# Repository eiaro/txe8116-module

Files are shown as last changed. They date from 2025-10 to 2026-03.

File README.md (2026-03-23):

# TXE8116 Module

Open-source hardware module for the TXE8116 — a 16-bit SPI I/O expander with two 8-bit ports, configurable push-pull/open-drain outputs, pull resistors, interrupt support, and per-pin glitch filtering.

## Repository Structure

```
txe8116-module/
├── hardware/          # KiCad schematic and PCB (CC BY-SA 4.0)
├── firmware/          # Driver and example code (MIT)
│   ├── esp32/         # ESP-IDF example
│   ├── zephyr/        # Zephyr RTOS examples
│   ├── raspberrypi/   # Python driver and C example
│   ├── arduino/       # Arduino example
│   └── beaglebone/    # BeagleBone C example
└── docs/              # Wiring guides
```

## Firmware

### ESP32 (ESP-IDF)

Uses the [`eiaro/txe81xx`](https://components.espressif.com/components/eiaro/txe81xx) component from the ESP component registry.

```bash
cd firmware/esp32/esp-idf/txe8116_idf
idf.py build flash monitor
```

See [`firmware/esp32/esp-idf/txe8116_idf/README.md`](firmware/esp32/esp-idf/txe8116_idf/README.md).

### Zephyr RTOS

Uses the [`xylon-labs/zephyr-txe81xx`](https://github.com/xylon-labs/zephyr-txe81xx) driver module.

| Example | Description |
|---|---|
| [`firmware/zephyr/basic_gpio`](firmware/zephyr/basic_gpio/README.md) | Polling — LED mirrors button state |
| [`firmware/zephyr/gpio_interrupt`](firmware/zephyr/gpio_interrupt/README.md) | Interrupt-driven — LED toggles on button events |

```bash
west build -b nucleo_l476rg firmware/zephyr/basic_gpio
```

### Raspberry Pi (Python)

```bash
cd firmware/raspberrypi/python
python3 example.py
```

See [`firmware/raspberrypi/python/README.md`](firmware/raspberrypi/python/README.md).

## Hardware

KiCad 8.x project in [`hardware/txe8116-module/`](hardware/txe8116-module/README.md). Fabrication files (Gerbers, BOM, pick & place) are in `hardware/txe8116-module/fabrication/`.

## License

- **Hardware** (`hardware/`): [CC BY-SA 4.0](hardware/LICENSE)
- **Firmware / Software** (`firmware/`): [MIT](firmware/LICENSE)

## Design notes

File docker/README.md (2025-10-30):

# KiBot Docker Image for txe8116-module

This Docker image contains KiBot with KiCad 9.0.5 to ensure consistent
versioning between local development and CI/CD.

## Why?

We use KiCad 9.0.5 locally, but the standard KiBot Docker image uses 9.0.1,
which can cause incompatibility issues.

## Usage

### Local Development
```bash
# Build the image
docker build -t txe8116-kibot:latest docker/

# Run ERC/DRC
docker run --rm -v $(pwd):/workspace txe8116-kibot:latest \
  -c hardware/kibot.yaml \
  -b hardware/txe8116-module.kicad_pcb
```

### In CI/CD
The image is automatically built and published to GitHub Container Registry
when changes are pushed to the main branch.

## Updating KiCad Version

Edit `Dockerfile` and update the KiCad version as needed.

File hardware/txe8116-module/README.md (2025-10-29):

# TXE8116 Module — Hardware

KiCad project for the TXE8116 SPI 16-bit I/O expander module.

## Layout
- `kicad/` – editable sources (schematic, PCB, libs)
- `fabrication/` – Gerbers, drill, BOM, pick&place (for production)
- `docs/` – PDFs, renders, drawings

## Build notes
- KiCad 8.x recommended
- Generate fab files to `fabrication/` (Gerbers, drill, BOM, pos)
- Export PDFs of schematic/PCB to `docs/pdf/`

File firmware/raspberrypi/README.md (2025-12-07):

# TXE8116 - Raspberry Pi

Simple guide to get started with TXE8116 on Raspberry Pi.

## Quick Start

### 1. Enable SPI

```bash
sudo raspi-config
```
- Navigate to: **Interface Options → SPI → Enable**
- Reboot: `sudo reboot`

### 2. Verify SPI

After reboot:
```bash
ls /dev/spidev*
```
You should see `/dev/spidev0.0` and `/dev/spidev0.1`

### 3. Wiring

Connect TXE8116 to Raspberry Pi:

| TXE8116 Pin | RPi Pin | BCM GPIO | Function |
|---|---|---|---|
| VCC | Pin 1 | - | 3.3V Power |
| GND | Pin 6 | - | Ground |
| CS | Pin 24 | GPIO 8 | SPI CE0 |
| SCK | Pin 23 | GPIO 11 | SPI SCLK |
| SDI (MOSI) | Pin 19 | GPIO 10 | SPI MOSI |
| SDO (MISO) | Pin 21 | GPIO 9 | SPI MISO |
| INT | Pin 11 | GPIO 17 | Interrupt (optional*) |
| RESET | Pin 15 | GPIO 22 | Reset (optional*) |

*Note: INT and RESET pins are optional but current hardware revision requires external pull-up resistors if not used. See [#8](https://github.com/eiaro/txe8116-module/issues/8) and [#9](https://github.com/eiaro/txe8116-module/issues/9) for details.

### 4. Test with Python

Install dependencies:
```bash
pip3 install spidev
```

Run example:
```bash
cd python/examples
python3 txe8116_spidev_example.py
```

## Languages & Frameworks

- **[Python](python/)** - High-level examples with spidev
- **[C](c/)** - Direct SPI access with `/dev/spidev`

## Troubleshooting

**SPI not enabled:**
```bash
# Check if SPI is enabled
lsmod | grep spi
# Should show: spi_bcm2835

# Alternative: add to /boot/config.txt
dtparam=spi=on
```

**Permission denied:**
```bash
# Add user to spi group
sudo usermod -a -G spi $USER
# Logout and login again
```

**Device not responding:**
- Check wiring (especially GND connection)
- Verify VCC is 3.3V (not 5V!)
- Measure SPI clock frequency with oscilloscope
- Check TXE8116 datasheet for timing requirements

## Resources

- [Raspberry Pi SPI Documentation](https://www.raspberrypi.com/documentation/computers/raspberry-pi.html#serial-peripheral-interface-spi)
- [TXE8116 Datasheet](../../docs/datasheet/)
- [Wiring Diagram](../../docs/wiring_rpi.md)

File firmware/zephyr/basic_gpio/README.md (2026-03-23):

# TXE8116 Basic GPIO Sample (Zephyr)

Minimal Zephyr sample for the TXE8116 16-bit SPI I/O expander. Reads a button and mirrors the state to an LED in a polling loop.

## Requirements

- Zephyr RTOS v3.6 or later
- [xylon-labs/zephyr-txe81xx](https://github.com/xylon-labs/zephyr-txe81xx) driver module

## Hardware Setup

Board overlay provided for **STM32 Nucleo-L476RG** (`boards/nucleo_l476rg.overlay`).

| Signal | Pin |
|---|---|
| SPI1 CS | PA4  |
| RESET | PC6  |
| INT | PC7  |

| TXE Pin | Function |
|---|---|
| Pin 0 | LED (active low) |
| Pin 8 | Switch (active high, pull-down) |

## Build & Flash

```bash
west build -b nucleo_l476rg
west flash
```

## Behaviour

LED follows button state with a 50 ms polling interval.

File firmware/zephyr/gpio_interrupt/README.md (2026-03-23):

# TXE8116 GPIO Interrupt Sample (Zephyr)

Zephyr sample demonstrating interrupt-driven GPIO with the TXE8116 16-bit SPI I/O expander. The LED toggles on each button press and release.

## Requirements

- Zephyr RTOS v3.6 or later
- [xylon-labs/zephyr-txe81xx](https://github.com/xylon-labs/zephyr-txe81xx) driver module

## Hardware Setup

Board overlay provided for **STM32 Nucleo-L476RG** (`boards/nucleo_l476rg.overlay`).

| Signal | Pin |
|---|---|
| SPI1 CS | PA4  |
| RESET | PC6  |
| INT | PC7  |

| TXE Pin | Function |
|---|---|
| Pin 0 | LED (active low) |
| Pin 8 | Switch (active high, pull-down) |

A hardware glitch filter is enabled on the switch pin via `glitch-filter-pins` in the overlay.

## Build & Flash

```bash
west build -b nucleo_l476rg
west flash
```

## Behaviour

- Button press → LED toggles, logs `Switch: PRESSED`
- Button release → LED toggles, logs `Switch: RELEASED`
- Main thread sleeps indefinitely; all activity is interrupt-driven

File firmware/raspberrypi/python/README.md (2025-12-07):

# TXE8116 Python Driver

Python library for the TXE8116 16-bit SPI I/O expander on Raspberry Pi.

## Installation

```bash
# Install dependencies
sudo apt-get install python3-spidev python3-rpi.gpio

# Enable SPI
sudo raspi-config
# Interface Options → SPI → Enable
```

## Hardware Setup

### SPI Connections
- **VCC** → 3.3V
- **GND** → GND
- **SCLK** → GPIO11 (SCLK)
- **MOSI** → GPIO10 (MOSI)
- **MISO** → GPIO9 (MISO)
- **CS** → GPIO8 (CE0)
- **RESET** → GPIO22 (optional, recommended)

## Usage

```python
from txe8116 import TXE8116

# Initialize
io = TXE8116(bus=0, device=0, reset_pin=22)

# Configure Port 0 as all outputs
io.configure_port(port=0, direction=0xFF, push_pull=0x00)

# Write patterns
io.write_port(port=0, value=0xFF)  # All HIGH
io.write_port(port=0, value=0x00)  # All LOW

# Individual pin control
io.set_pin(port=0, pin=0)    # P0.0 HIGH
io.clear_pin(port=0, pin=0)  # P0.0 LOW
io.toggle_pin(port=0, pin=0) # Toggle P0.0

# Read inputs (set direction=0x00 first)
value = io.read_port(port=0)

# Clean up
io.close()
```

## Example

Run the example:
```bash
python3 example.py
```

## Notes

- **Direction**: `1` = output, `0` = input
- **Push-pull**: `0` = push-pull (default), `1` = open-drain
- **Ports**: Port 0 and Port 1, 8 pins each (16 total)

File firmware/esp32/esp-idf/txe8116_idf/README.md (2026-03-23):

# TXE8116 ESP-IDF Example

ESP-IDF example for the TXE8116 16-bit SPI I/O expander using the [`eiaro/txe81xx`](https://components.espressif.com/components/eiaro/txe81xx) component from the ESP component registry.

Demonstrates interrupt-driven I/O: a button on TXE Port 1 controls the blink rate of an LED on TXE Port 0.

## Requirements

- ESP-IDF v5.0 or later
- ESP32-C6 (or adjust pin definitions in `main/txe8116_idf.c`)

## Hardware Setup

| Signal | ESP32 GPIO |
|---|---|
| MOSI | GPIO7 |
| MISO | GPIO2 |
| CLK | GPIO6 |
| CS | GPIO10 |
| RESET  | GPIO3 |
| INT | GPIO4 |

| TXE Pin | Function |
|---|---|
| P0.0 | LED (active low) |
| P1.1 | Switch (active high, pull-down) |

## Build & Flash

```bash
idf.py build
idf.py flash monitor
```

The component manager will fetch `eiaro/txe81xx` automatically on first build.

## Behaviour

- LED blinks slowly (300 ms) when button is released
- LED blinks fast (100 ms) when button is held
- Button state is read via TXE interrupt — no polling

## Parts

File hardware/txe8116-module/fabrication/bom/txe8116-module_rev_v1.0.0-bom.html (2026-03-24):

 | KiBot variants example
 | Schematic: txe8116-module Variant: default Revision: v1.0.0 Date: 2026-03-24_20-05-20 KiCad Version: 9.0.5+1 | Component Groups: 5 Component Count: 28 (per PCB) Fitted Components: 28 (per PCB) Number of PCBs: 1 Total Components: 28 (for 1 PCBs)
Row | References | Quantity Per PCB | Value | Footprint
1 | C3 | 1 | 100 nF | C_0603_1608Metric
2 | C4 | 1 | 4.7 µF | C_0603_1608Metric
3 | D1 D2 D3 D4 D5 D6 D7 D8 D9 D10 D11 D12 D13 D14 D15 D16 D17 D18 D19 D20 D21 D22 D23 | 23 | ESD9B5.0ST5G | D_SOD-923
4 | R1 R2 | 2 | 10 kΩ | R_0603_1608Metric
5 | U1 | 1 | TXE8116 | Texas_DGS0024A_TSSOP-24_3x6.1mm_P0.5mm
Color reference for columns:
KiCad Fields (default)
Generated Fields
User Fields

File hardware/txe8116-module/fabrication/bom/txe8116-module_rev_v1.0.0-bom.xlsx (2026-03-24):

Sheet: BoM
 |  | KiBot variants example
 |  | Schematic: | txe8116-module | Component Groups: | 5
 |  | Variant: | default | Component Count: | 28
 |  | Revision: | v1.0.0 | Fitted Components: | 28
 |  | Date: | 2026-03-24_20-05-20 | Number of PCBs: | 1
 |  | KiCad Version: | 9.0.5+1 | Total Components: | 28
Row | References | Quantity Per PCB | Value | Footprint
1 | C3 | 1 | 100 nF | C_0603_1608Metric
2 | C4 | 1 | 4.7 µF | C_0603_1608Metric
3 | D1 D2 D3 D4 D5 D6 D7 D8 D9 D10 D11 D12 D13 D14 D15 D16 D17 D18 D19 D20 D21 D22 D23 | 23 | ESD9B5.0ST5G | D_SOD-923
4 | R1 R2 | 2 | 10 kΩ | R_0603_1608Metric
5 | U1 | 1 | TXE8116 | Texas_DGS0024A_TSSOP-24_3x6.1mm_P0.5mm

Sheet: Colors
Columns colors
KiCad Fields (default)
Generated Fields
User Fields

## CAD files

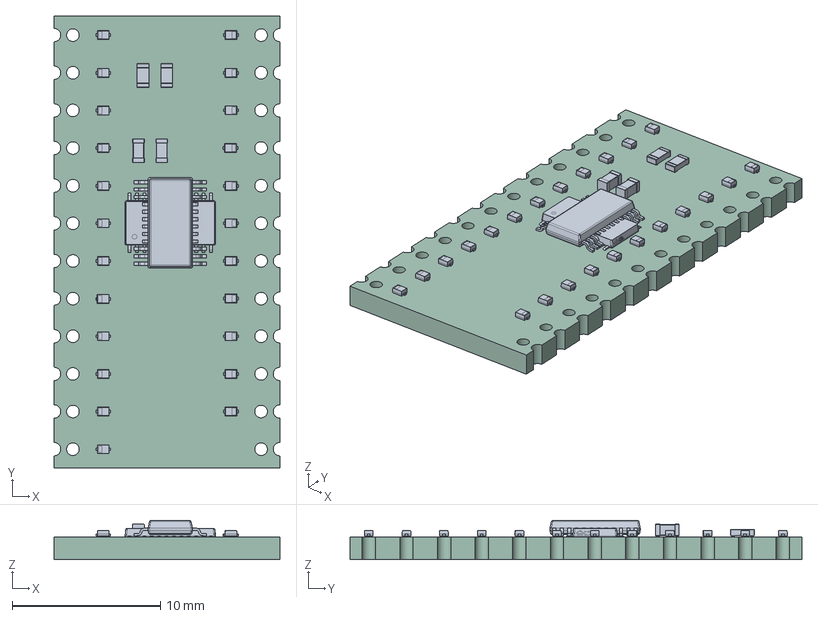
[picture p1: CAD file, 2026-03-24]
hardware/txe8116-module/docs/3d/txe8116-module_rev_v1.0.0-3D.step
15.2 x 30.5 x 2.64 mm
C_0603_1608Metric x 2
D_SOD-923 x 23
R_0603_1608Metric x 2
Texas_DGS0024A_TSSOP-24_3x6.1mm_P0.5mm
BODY-VSSOP
LEAD-VSSOP x 24
kibot_dck8frig_PCB

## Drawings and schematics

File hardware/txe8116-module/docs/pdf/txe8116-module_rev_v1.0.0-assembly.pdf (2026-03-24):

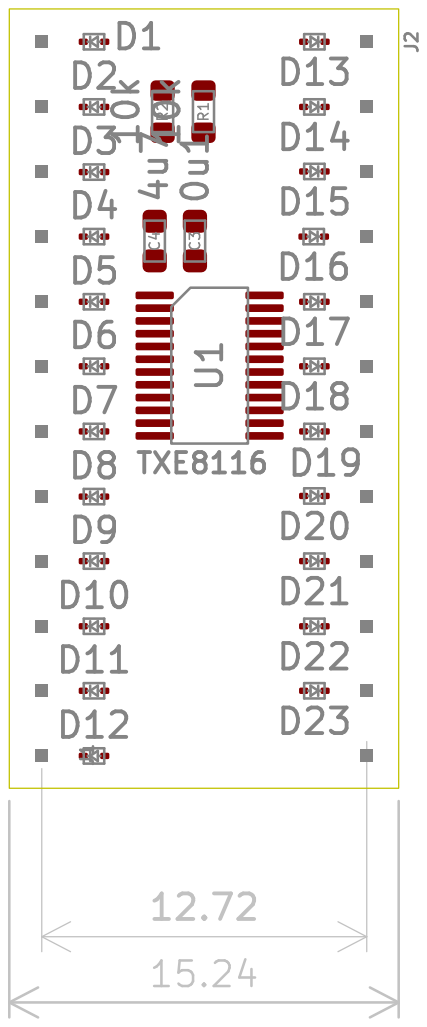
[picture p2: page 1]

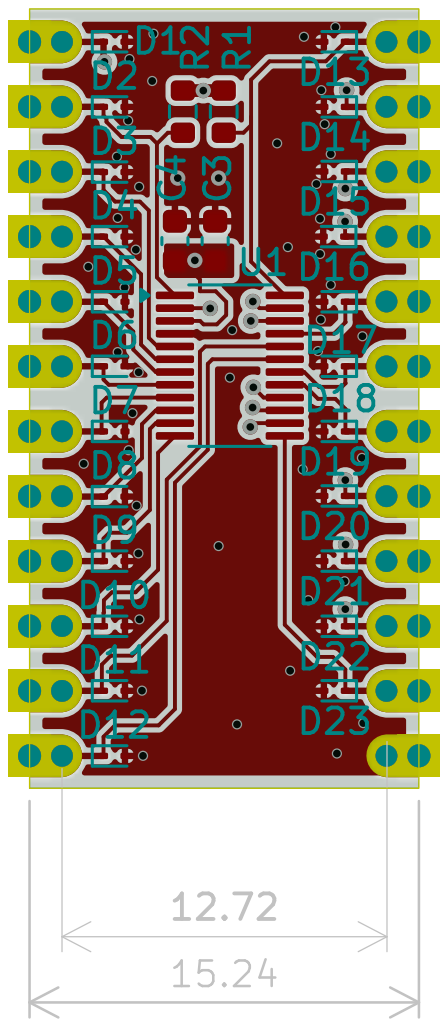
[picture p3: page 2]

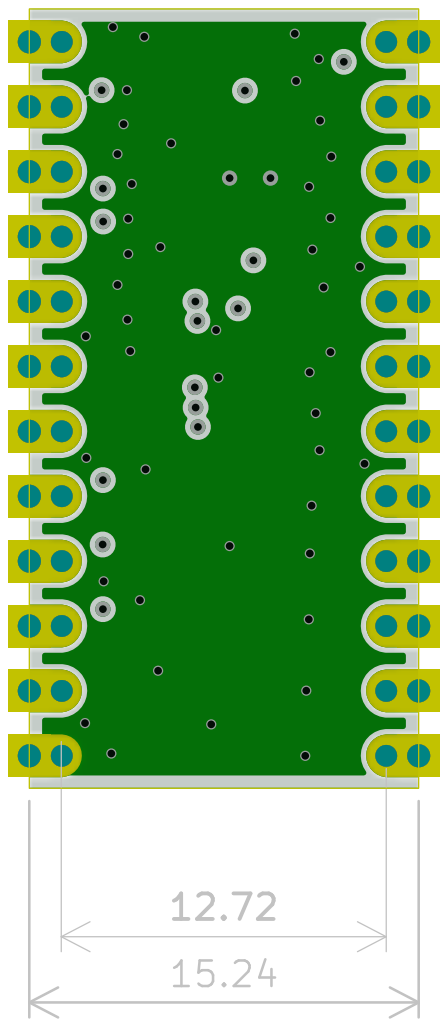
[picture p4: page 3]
AISLER Project; ID: ZZLMEGJE; Sheet:; Bottom layer; File: txe8116-module.kicad_pcb Title:

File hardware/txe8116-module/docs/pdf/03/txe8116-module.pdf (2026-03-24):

AISLER Project; ID: ZZLMEGJE; Sheet:; Bottom layer; File: txe8116-module.kicad_pcb Title:; Size: A4; Rev: v1.0.0; KiCad; E.D.A. 9.0.5+1 + KiBot v1.8.4; Date: 2026-03-24_20-05-22

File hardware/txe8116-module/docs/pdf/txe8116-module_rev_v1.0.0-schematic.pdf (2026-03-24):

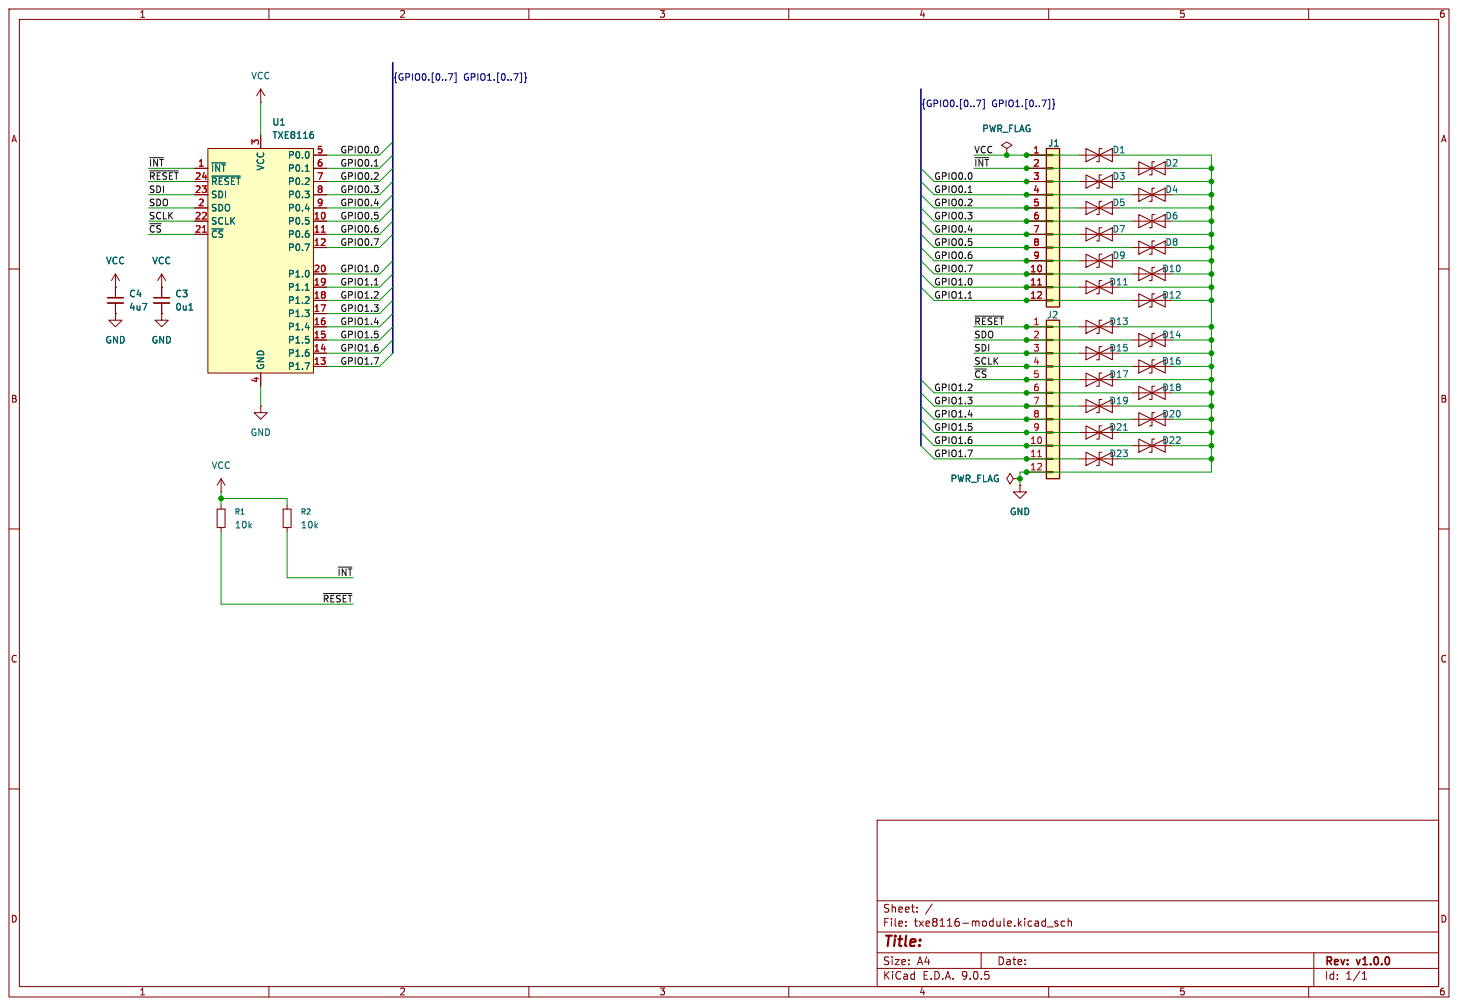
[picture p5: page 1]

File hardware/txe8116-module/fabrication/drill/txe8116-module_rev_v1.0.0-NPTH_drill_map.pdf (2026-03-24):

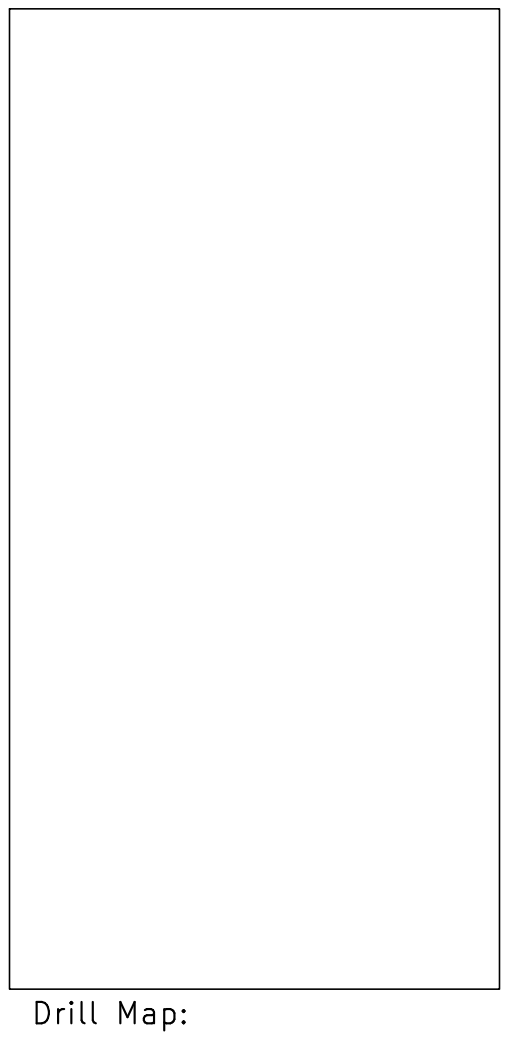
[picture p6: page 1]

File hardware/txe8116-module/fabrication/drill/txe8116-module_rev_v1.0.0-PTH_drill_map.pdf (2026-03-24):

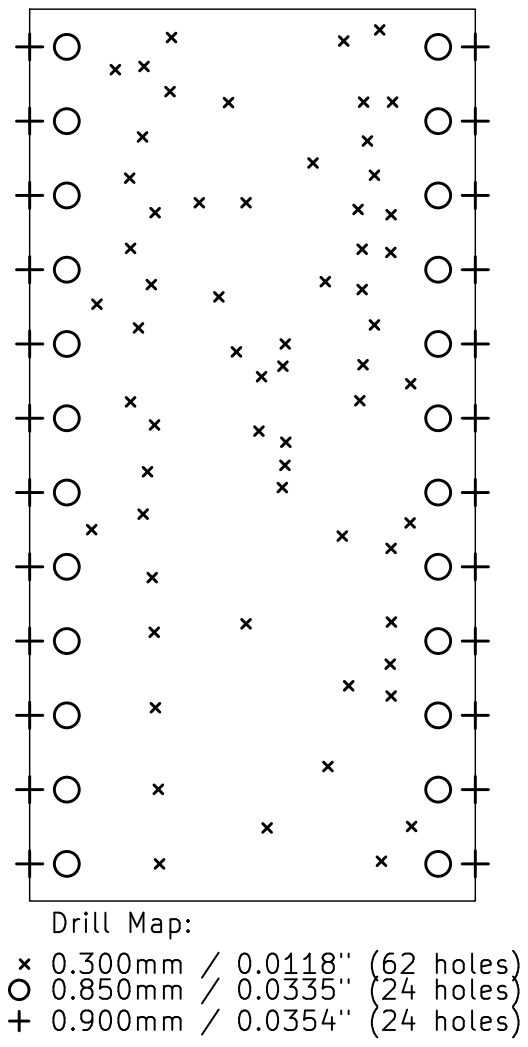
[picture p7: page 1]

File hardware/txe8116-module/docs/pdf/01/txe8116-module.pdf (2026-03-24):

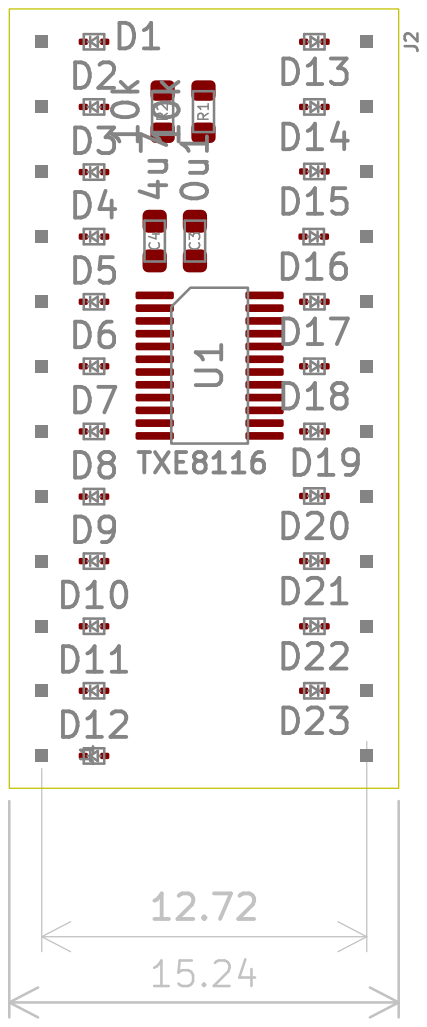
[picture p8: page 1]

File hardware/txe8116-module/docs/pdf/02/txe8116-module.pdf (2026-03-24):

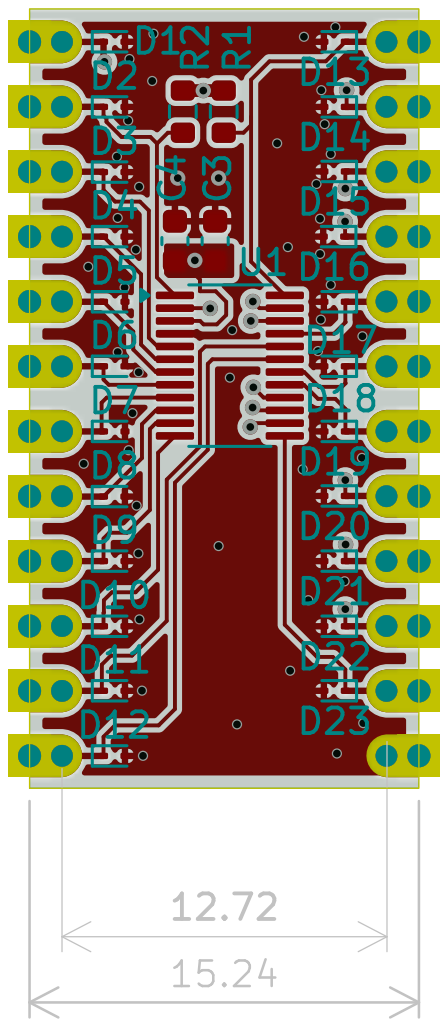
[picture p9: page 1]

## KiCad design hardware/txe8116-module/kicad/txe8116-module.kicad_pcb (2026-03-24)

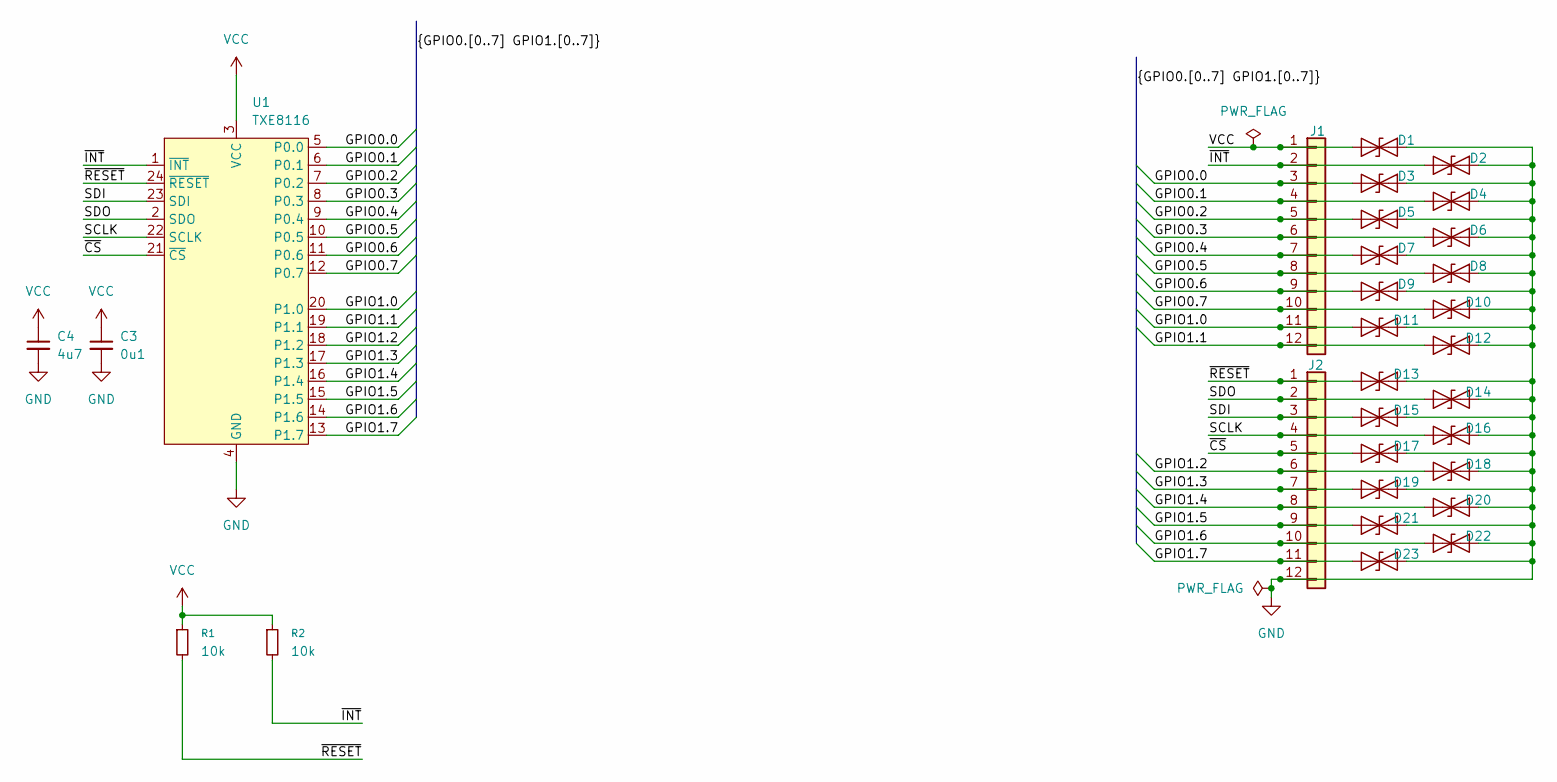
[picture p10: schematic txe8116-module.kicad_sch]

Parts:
C3: 0u1; C_0603_1608Metric
C4: 4u7; C_0603_1608Metric
D1, D2, D3, D4, D5, D6, D7, D8, D9, D10, D11, D12, D13, D14, D15, D16, D17, D18, D19, D20, D21, D22, D23: ESD9B5.0ST5G; D_SOD-923; MPN ESD9B5.0ST5G
J1: Conn_01x12; 1x12_P2.54mm_Castellated_Mirrored
J2: Conn_01x12; 1x12_P2.54mm_Castellated
R1, R2: 10k; R_0603_1608Metric
U1: TXE8116; Texas_DGS0024A_TSSOP-24_3x6.1mm_P0.5mm; MPN TXE8116DGSR

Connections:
/GPIO0.0: D3.1 (A1), J1.3, U1.5 (P0.0)
/GPIO0.1: D4.1 (A1), J1.4, U1.6 (P0.1)
/GPIO0.2: D5.1 (A1), J1.5, U1.7 (P0.2)
/GPIO0.3: D6.1 (A1), J1.6, U1.8 (P0.3)
/GPIO0.4: D7.1 (A1), J1.7, U1.9 (P0.4)
/GPIO0.5: D8.1 (A1), J1.8, U1.10 (P0.5)
/GPIO0.6: D9.1 (A1), J1.9, U1.11 (P0.6)
/GPIO0.7: D10.1 (A1), J1.10, U1.12 (P0.7)
/GPIO1.0: D11.1 (A1), J1.11, U1.20 (P1.0)
/GPIO1.1: D12.1 (A1), J1.12, U1.19 (P1.1)
/GPIO1.2: D18.1 (A1), J2.6, U1.18 (P1.2)
/GPIO1.3: D19.1 (A1), J2.7, U1.17 (P1.3)
/GPIO1.4: D20.1 (A1), J2.8, U1.16 (P1.4)
/GPIO1.5: D21.1 (A1), J2.9, U1.15 (P1.5)
/GPIO1.6: D22.1 (A1), J2.10, U1.14 (P1.6)
/GPIO1.7: D23.1 (A1), J2.11, U1.13 (P1.7)
/SCLK: D16.1 (A1), J2.4, U1.22 (SCLK)
/SDI: D15.1 (A1), J2.3, U1.23 (SDI)
/SDO: D14.1 (A1), J2.2, U1.2 (SDO)
/~CS: D17.1 (A1), J2.5, U1.21 (~CS)
/~INT: D2.1 (A1), J1.2, R2.2, U1.1 (~INT)
/~RESET: D13.1 (A1), J2.1, R1.2, U1.24 (~RESET)
GND: C3.2, C4.2, D1.2 (A2), D2.2 (A2), D3.2 (A2), D4.2 (A2), D5.2 (A2), D6.2 (A2), D7.2 (A2), D8.2 (A2), D9.2 (A2), D10.2 (A2), D11.2 (A2), D12.2 (A2), D13.2 (A2), D14.2 (A2), D15.2 (A2), D16.2 (A2), D17.2 (A2), D18.2 (A2), D19.2 (A2), D20.2 (A2), D21.2 (A2), D22.2 (A2), D23.2 (A2), J2.12, U1.4 (GND)
VCC: C3.1, C4.1, D1.1 (A1), J1.1, R1.1, R2.1, U1.3 (VCC)

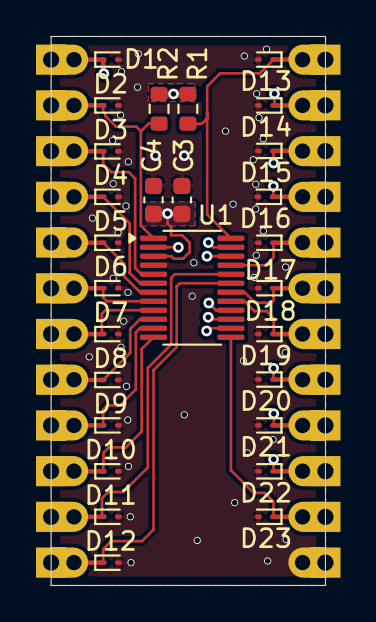
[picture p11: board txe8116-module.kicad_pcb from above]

Board: 4 copper layers, 15.2 x 30.5 mm, 30 parts (0 on the bottom side), 24 nets.

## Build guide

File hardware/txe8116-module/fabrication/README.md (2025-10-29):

# Fabrication files (Gerbers/Drill/BOM/Pos)

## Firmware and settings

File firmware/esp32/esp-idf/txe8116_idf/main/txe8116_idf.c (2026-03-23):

#include <stdio.h>
#include <stdint.h>
#include <stdbool.h>

#include "freertos/FreeRTOS.h"
#include "freertos/task.h"

#include "driver/gpio.h"
#include "driver/spi_master.h"
#include "esp_err.h"
#include "esp_log.h"

#include "txe81xx.h"

static const char *TAG = "irq_example";

#define TXE_RESET_LOW_MS       5
#define TXE_RESET_HIGH_MS      10
#define BLINK_FAST_MS          100
#define BLINK_SLOW_MS          300
#define DEBUG_LOG_DIVIDER      10

// ---------------- ESP32 wiring ----------------
#define PIN_NUM_MOSI   GPIO_NUM_7
#define PIN_NUM_MISO   GPIO_NUM_2
#define PIN_NUM_CLK    GPIO_NUM_6
#define PIN_NUM_CS     GPIO_NUM_10
#define PIN_NUM_RESET  GPIO_NUM_3
#define PIN_NUM_INT    GPIO_NUM_4   // TXE INT pin -> ESP GPIO4

// ---------------- TXE pins used ----------------
// LED on TXE P0.0, LED has pull-up => active LOW
#define LED_PORT       TXE_PORT0
#define LED_MASK       0x01

// Switch on TXE P1.1, switch closes to 3.3V => use pull-down => pressed = 1
#define SW_PORT        TXE_PORT1
#define SW_MASK        0x02

static volatile uint8_t g_pressed = 0;

static inline bool sw_is_pressed(uint8_t value)
{
    return (value & SW_MASK) != 0;
}

static inline TickType_t blink_delay_ticks(void)
{
    return pdMS_TO_TICKS(g_pressed ? BLINK_FAST_MS : BLINK_SLOW_MS);
}

// Simple read-modify-write helper for an 8-bit TXE register
static void hw_reset_txe(void)
{
    gpio_config_t io = {
        .pin_bit_mask = 1ULL << PIN_NUM_RESET,
        .mode = GPIO_MODE_OUTPUT,
        .pull_up_en = GPIO_PULLUP_DISABLE,
        .pull_down_en = GPIO_PULLDOWN_DISABLE,
        .intr_type = GPIO_INTR_DISABLE,
    };
    ESP_ERROR_CHECK(gpio_config(&io));

    gpio_set_level(PIN_NUM_RESET, 0);
    vTaskDelay(pdMS_TO_TICKS(TXE_RESET_LOW_MS));

    gpio_set_level(PIN_NUM_RESET, 1);
    vTaskDelay(pdMS_TO_TICKS(TXE_RESET_HIGH_MS));
}

static void irq_cb(txe81xx_port_t port, uint8_t flags, uint8_t state, void *ctx)
{
    (void)ctx;

    if (port == SW_PORT && (flags & SW_MASK)) {
        g_pressed = sw_is_pressed(state) ? 1 : 0;
        ESP_EARLY_LOGI(TAG, "IRQ: flags=0x%02X state=0x%02X pressed=%u", flags, state, g_pressed);
    }
}

static void configure_led_and_switch(txe81xx_handle_t io, uint8_t *out_p0)
{
    ESP_ERROR_CHECK(txe81xx_update_pushpull_od(io, LED_PORT, LED_MASK, 0));
    ESP_ERROR_CHECK(txe81xx_update_direction(io, LED_PORT, LED_MASK, 0));

    ESP_ERROR_CHECK(txe81xx_read_outputs(io, LED_PORT, out_p0));
    *out_p0 |= LED_MASK;
    ESP_ERROR_CHECK(txe81xx_write_outputs(io, LED_PORT, *out_p0));

    ESP_ERROR_CHECK(txe81xx_update_direction(io, SW_PORT, 0, SW_MASK));
    ESP_ERROR_CHECK(txe81xx_update_pull_enable_mask(io, SW_PORT, SW_MASK, 0));
    ESP_ERROR_CHECK(txe81xx_update_pull_select_mask(io, SW_PORT, 0, SW_MASK));
    ESP_ERROR_CHECK(txe81xx_update_glitch_filter(io, SW_PORT, SW_MASK, 0));
}

static void configure_txe_interrupts(txe81xx_handle_t io)
{
    ESP_ERROR_CHECK(txe81xx_irq_configure_port(io, SW_PORT, true, 0xFF));
    ESP_ERROR_CHECK(txe81xx_irq_enable_pins(io, SW_PORT, SW_MASK));
    ESP_ERROR_CHECK(txe81xx_irq_clear_pending(io));
}

static void log_periodic_debug(txe81xx_handle_t io)
{
    uint8_t flags = 0;
    uint8_t port_status = 0;
    uint8_t raw = 0;

    ESP_ERROR_CHECK(txe81xx_irq_read_port_status(io, &port_status));
    ESP_ERROR_CHECK(txe81xx_irq_read_flags(io, TXE_PORT1, &flags));
    ESP_ERROR_CHECK(txe81xx_read_inputs(io, SW_PORT, &raw));

    ESP_LOGI(TAG,
             "GPIO4=%d rawP1=0x%02X flagsP1=0x%02X portStat=0x%02X pressed=%u",
             gpio_get_level(PIN_NUM_INT), raw, flags, port_status, g_pressed);
}

void app_main(void)
{
    ESP_LOGI(TAG, "Starting TXE IRQ example");

    // ---------- Reset TXE ----------
    hw_reset_txe();

    // ---------- Init SPI bus ----------
    spi_bus_config_t buscfg = {
        .mosi_io_num = PIN_NUM_MOSI,
        .miso_io_num = PIN_NUM_MISO,
        .sclk_io_num = PIN_NUM_CLK,
        .quadwp_io_num = -1,
        .quadhd_io_num = -1,
    };
    ESP_ERROR_CHECK(spi_bus_initialize(SPI2_HOST, &buscfg, SPI_DMA_CH_AUTO));

    // ---------- Init TXE component ----------
    txe81xx_handle_t io;
    txe81xx_spi_config_t cfg = {
        .host = SPI2_HOST,
        .cs_gpio = PIN_NUM_CS,
        .clock_hz = 100 * 1000,
        .mode = 0,               // datasheet
        .queue_size = 1,
        .use_polling = true,
        .chip = TXE_CHIP_8116,
    };
    ESP_ERROR_CHECK(txe81xx_init_spi(&cfg, &io));

    // ---------- Clear POR / fault ----------
    uint8_t fault = 0;
    ESP_ERROR_CHECK(txe81xx_read_fault_status(io, &fault));
    ESP_LOGI(TAG, "FAULT STATUS = 0x%02X", fault);

    // ---------- Sanity: read device id ----------
    uint8_t id = 0xFF;
    ESP_ERROR_CHECK(txe81xx_read_device_id(io, &id));
    ESP_LOGI(TAG, "Device ID: %u (0x%02X)", id, id);

    uint8_t out_p0 = 0;
    configure_led_and_switch(io, &out_p0);

    configure_txe_interrupts(io);

    ESP_LOGI(TAG, "GPIO4 before IRQ install = %d", gpio_get_level(PIN_NUM_INT));

    // ---------- Install ESP-side IRQ ----------
    txe81xx_irq_config_t irq_cfg = {
        .int_gpio = PIN_NUM_INT,   // GPIO4
        .active_low = true,        // inverted / active-low
        .cb = irq_cb,
        .user_ctx = NULL,
        .task_stack = 3072,
        .task_prio = 10,
        .task_core = -1,
    };
    ESP_ERROR_CHECK(txe81xx_irq_install(io, &irq_cfg));

    // ---------- Initial raw switch read ----------
    uint8_t in_p1 = 0;
    ESP_ERROR_CHECK(txe81xx_read_inputs(io, SW_PORT, &in_p1));
    g_pressed = sw_is_pressed(in_p1) ? 1 : 0;

    ESP_LOGI(TAG, "Initial switch raw P1=0x%02X pressed=%u", in_p1, g_pressed);

    // ---------- Main loop ----------
    while (1) {
        // Blink LED. Faster when button pressed.
        // LED active low:
        //  bit0 = 0 -> ON
        //  bit0 = 1 -> OFF

        // ON
        out_p0 &= (uint8_t)~LED_MASK;
        ESP_ERROR_CHECK(txe81xx_write_outputs(io, LED_PORT, out_p0));
        vTaskDelay(blink_delay_ticks());

        // OFF
        out_p0 |= LED_MASK;
        ESP_ERROR_CHECK(txe81xx_write_outputs(io, LED_PORT, out_p0));
        vTaskDelay(blink_delay_ticks());

        // Optional slow debug
        static int dbg_div = 0;
        dbg_div++;
        if (dbg_div >= DEBUG_LOG_DIVIDER) {
            dbg_div = 0;
            log_periodic_debug(io);
        }
    }
}

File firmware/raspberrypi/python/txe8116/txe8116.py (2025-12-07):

"""
TXE8116 - 16-bit SPI I/O Expander Driver for Raspberry Pi
"""

import spidev
import RPi.GPIO as GPIO
import time


class TXE8116:
    """Simple driver for TXE8116 16-bit I/O expander"""
    
    # Register addresses
    SCRATCH = 0x00
    DEVICE_ID = 0x01
    INPUT = 0x02
    OUTPUT = 0x03
    DIRECTION = 0x04
    POLARITY = 0x05
    PUSH_PULL = 0x06
    
    # Ports
    PORT0 = 0x00
    PORT1 = 0x01
    
    def __init__(self, bus=0, device=0, reset_pin=None, speed_hz=500000):
        """
        Initialize TXE8116
        
        Args:
            bus: SPI bus number (usually 0)
            device: SPI device (0 = CE0/GPIO8, 1 = CE1/GPIO7)
            reset_pin: BCM GPIO pin for reset (optional, recommended)
            speed_hz: SPI clock speed (default 500kHz)
        """
        self.spi = spidev.SpiDev()
        self.spi.open(bus, device)
        self.spi.max_speed_hz = speed_hz
        self.spi.mode = 0  # CPOL=0, CPHA=0
        
        self.reset_pin = reset_pin
        if reset_pin:
            GPIO.setmode(GPIO.BCM)
            GPIO.setup(reset_pin, GPIO.OUT)
            self.reset()
    
    def reset(self):
        """Hardware reset via GPIO pin"""
        if self.reset_pin:
            GPIO.output(self.reset_pin, GPIO.LOW)
            time.sleep(0.01)
            GPIO.output(self.reset_pin, GPIO.HIGH)
            time.sleep(0.1)
    
    def _transfer(self, register, port, data, multi_port=False):
        """
        Write to register and return previous value
        
        Args:
            register: Register address (0x00-0x1F)
            port: Port number (0 or 1)
            data: Data byte to write
            multi_port: Enable multi-port mode
            
        Returns:
            Previous register value
        """
        cmd_byte = register & 0x1F
        port_byte = (port << 4) & 0x70
        m_bit = 0x01 if multi_port else 0x00
        
        rx = self.spi.xfer2([cmd_byte, port_byte + m_bit, data])
        return rx[2]
    
    def _read(self, register, port):
        """
        Read from register
        
        Args:
            register: Register address (0x00-0x1F)
            port: Port number (0 or 1)
            
        Returns:
            Register value
        """
        cmd_byte = (register & 0x1F) | 0x80  # Set read bit
        port_byte = (port << 4) & 0x70
        
        rx = self.spi.xfer2([cmd_byte, port_byte, 0x00])
        return rx[2]
    
    def read_device_id(self):
        """Read device ID (should return 0x00 for TXE8116)"""
        return self._read(self.DEVICE_ID, self.PORT0)
    
    def configure_port(self, port, direction=0xFF, push_pull=0x00):
        """
        Configure a port
        
        Args:
            port: Port number (0 or 1)
            direction: Direction bits (1=output, 0=input). Default: all outputs
            push_pull: Push-pull mode (0=push-pull, 1=open-drain). Default: all push-pull
        """
        self._transfer(self.DIRECTION, port, direction)
        self._transfer(self.PUSH_PULL, port, push_pull)
    
    def write_port(self, port, value):
        """
        Write to output port
        
        Args:
            port: Port number (0 or 1)
            value: 8-bit value to write (1=HIGH, 0=LOW)
        """
        self._transfer(self.OUTPUT, port, value)
    
    def read_port(self, port):
        """
        Read from input port
        
        Args:
            port: Port number (0 or 1)
            
        Returns:
            8-bit input value
        """
        return self._read(self.INPUT, port)
    
    def read_output(self, port):
        """
        Read current output register value
        
        Args:
            port: Port number (0 or 1)
            
        Returns:
            8-bit output value
        """
        return self._read(self.OUTPUT, port)
    
    def set_pin(self, port, pin):
        """
        Set a single pin HIGH
        
        Args:
            port: Port number (0 or 1)
            pin: Pin number (0-7)
        """
        current = self.read_output(port)
        self.write_port(port, current | (1 << pin))
    
    def clear_pin(self, port, pin):
        """
        Set a single pin LOW
        
        Args:
            port: Port number (0 or 1)
            pin: Pin number (0-7)
        """
        current = self.read_output(port)
        self.write_port(port, current & ~(1 << pin))
    
    def toggle_pin(self, port, pin):
        """
        Toggle a single pin
        
        Args:
            port: Port number (0 or 1)
            pin: Pin number (0-7)
        """
        current = self.read_output(port)
        self.write_port(port, current ^ (1 << pin))
    
    def close(self):
        """Clean up resources"""
        self.spi.close()
        if self.reset_pin:
            GPIO.cleanup()

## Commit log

2025-10-29 ci: add KiCad ERC/DRC workflow and KiBot config
2025-10-29 Skeleton files
    [txe8116-module.kicad_pcb, txe8116-module.kicad_sch]
2025-10-29 CI correction
    [txe8116-module.kicad_pcb, txe8116-module.kicad_sch]
2025-10-29 Add SMD resistor footprint and update schematic symbols for R_Small
    [txe8116-module.kicad_pcb, txe8116-module.kicad_sch]
2025-10-29 Add screw terminal footprint and update schematic
    - Introduced a new screw terminal footprint (WAGO 2601-1102) in the PCB layout.
    - Updated net connections for the new terminal block.
    - Modified the resistor value in the schematic to 100k.
    - Added a new connector symbol for the screw terminal in the schematic.
    - Enhanced the schematic with additional wire connections for better clarity.
    [txe8116-module.kicad_pcb, txe8116-module.kicad_sch]
2025-10-30 Add Dockerfile for KiBot with KiCad 9.0.5
2025-10-30 Update Dockerfile to use KiCad 9.0.5 image
2025-10-30 Update Dockerfile to install KiCad 9.x
    Added KiCad official Debian repository for version 9.x and updated installation commands.
2025-10-30 Enhance Dockerfile for KiCad installation
    Updated the Dockerfile to install additional KiCad packages and clean up unnecessary files.
2025-10-30 Added some components
    [txe8116-module.kicad_pcb, txe8116-module.kicad_sch]
2025-10-30 Add text variables for date and git hash in project configuration
    - Updated the text_variables section in the txe8116-module.kicad_pro file to include the current date and the git hash for better version tracking.
    [txe8116-module.kicad_pcb]
2025-10-30 Fix KiBot command arguments for ERC/DRC checks and update .gitignore for additional KiCad files
2025-11-02 Refactor code structure for improved readability and maintainability
    [txe8116-module.kicad_pcb, txe8116-module.kicad_sch]
2025-11-02 Update .gitignore and modify 3D model reference in Texas_DGS0024A footprint
2025-11-02 Add PWR_FLAG symbols to indicate power source for ERC checks
    [txe8116-module.kicad_sch]
2025-11-02 Asiler custom bridges causes DRC - Moved to a seperate layer - Move to Edge.Cut if manufactured at Aisler
    [txe8116-module.kicad_pcb]
2025-11-02 Remove variant title from PDF schematic and print options
2025-11-02 Adjust component properties and positions for improved layout and visibility
    [txe8116-module.kicad_pcb]
2025-11-02 Remove options section from Schematic PDF output configuration
2025-11-02 Refactor netclass assignments and update component properties for improved clarity
    [txe8116-module.kicad_sch]
2025-12-07 Add TXE8116 Python driver and example for Raspberry Pi integration
2025-12-07 Add TXE81xx driver header and implementation files for ESP32
2025-12-07 Add README for TXE8116 ESP-IDF driver with basic description
2026-03-23 refactor(esp32): switch to eiaro/txe81xx registry component
    Replace local driver copy with managed component from ESP component
    registry (eiaro/txe81xx ^1.0.1). Restructures project to standard
    ESP-IDF layout with main/ directory and idf_component.yml.
    [txe8116_idf.c]
2026-03-23 feat(zephyr): add basic_gpio and gpio_interrupt examples
    Two standalone Zephyr samples using the xylon-labs/zephyr-txe81xx
    driver module. Both include a Nucleo-L476RG board overlay.
2026-03-23 docs: add README for ESP32 IDF and Zephyr examples
2026-03-24 fix(hardware): add 10k pull-up resistors on RESET and INT per datasheet
    [txe8116-module.kicad_pcb, txe8116-module.kicad_sch]
2026-03-24 chore(hardware): set revision to v1.0.0
    [txe8116-module.kicad_pcb, txe8116-module.kicad_sch]
2026-03-24 chore: update generated docs and fabrication files
    [txe8116-module.kicad_pcb, txe8116-module_rev_v1.0.0-3D.step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]
2026-03-24 chore: exclude checks/ from version control (#25)
    KiBot uses checks/ as a temporary output directory during CI. The
    relevant files are copied to docs/ and fabrication/ by the workflow,
    so the checks/ directory itself should not be tracked.
    [txe8116-module_rev_v1.0.0-3D.step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]
2026-03-24 chore: update generated docs and fabrication files (#24)
    [txe8116-module_rev_v1.0.0-3D.step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]
